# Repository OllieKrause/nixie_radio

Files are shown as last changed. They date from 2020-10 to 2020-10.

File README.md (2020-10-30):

# nixie_radio
A simple FM radio that uses nixie tubes to display frequency and volume. The radio does use a custom PCB so I've included the Autodesk Eagle .brd, .sch, and custom.lib files. I also included the CAM files which are compatible with JLCPCB's cheapest 2 layer PCB manufacturing service.

I want to give a huge thanks to andykarpov for his TEA5767 FM radio library which I've used extensively throughout this project. https://github.com/andykarpov/TEA5767

While the code and hardware have been tested, this project is still very much a work in progress and the user experience has yet to be optimized. 

I hope to document this project in much greater detail once I'm satisfied with the first prototype. 

Questions, comments, suggestions?
Ollie.krause@gmail.com
https://bananascience.net

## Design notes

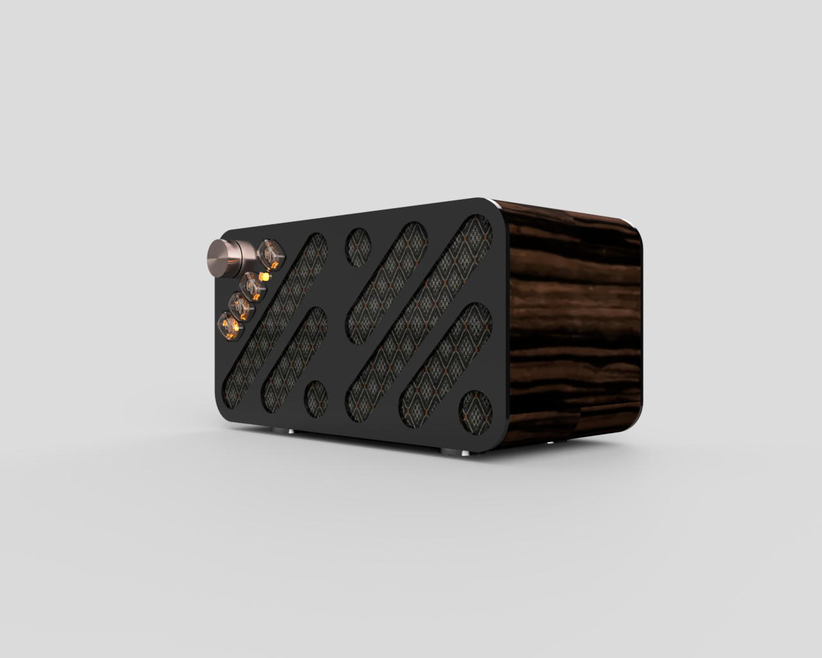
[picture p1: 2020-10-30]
Photos/Nixie Radio Concept 2.3.4.png

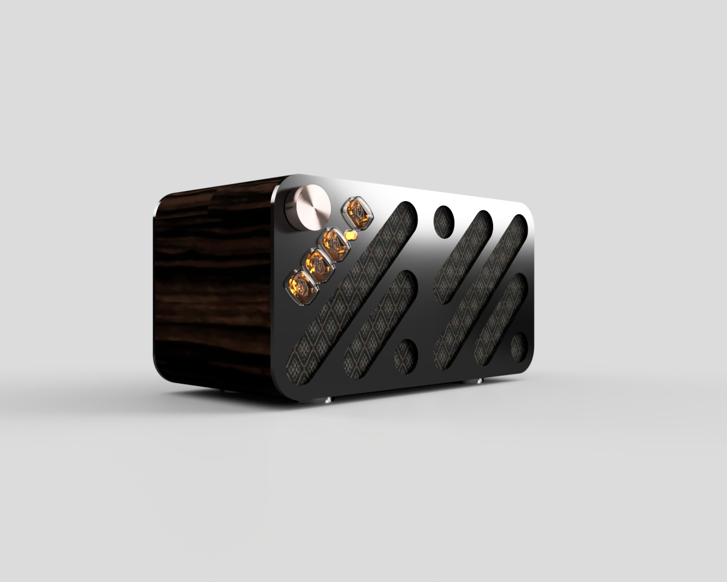
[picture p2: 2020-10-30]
Photos/Nixie Radio Concept 2.3.2.png

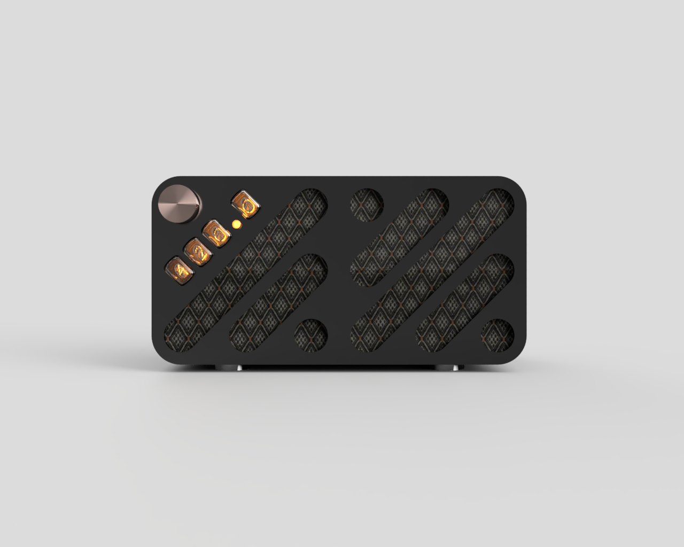
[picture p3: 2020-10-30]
Photos/Nixie Radio Concept 2.3.3.png

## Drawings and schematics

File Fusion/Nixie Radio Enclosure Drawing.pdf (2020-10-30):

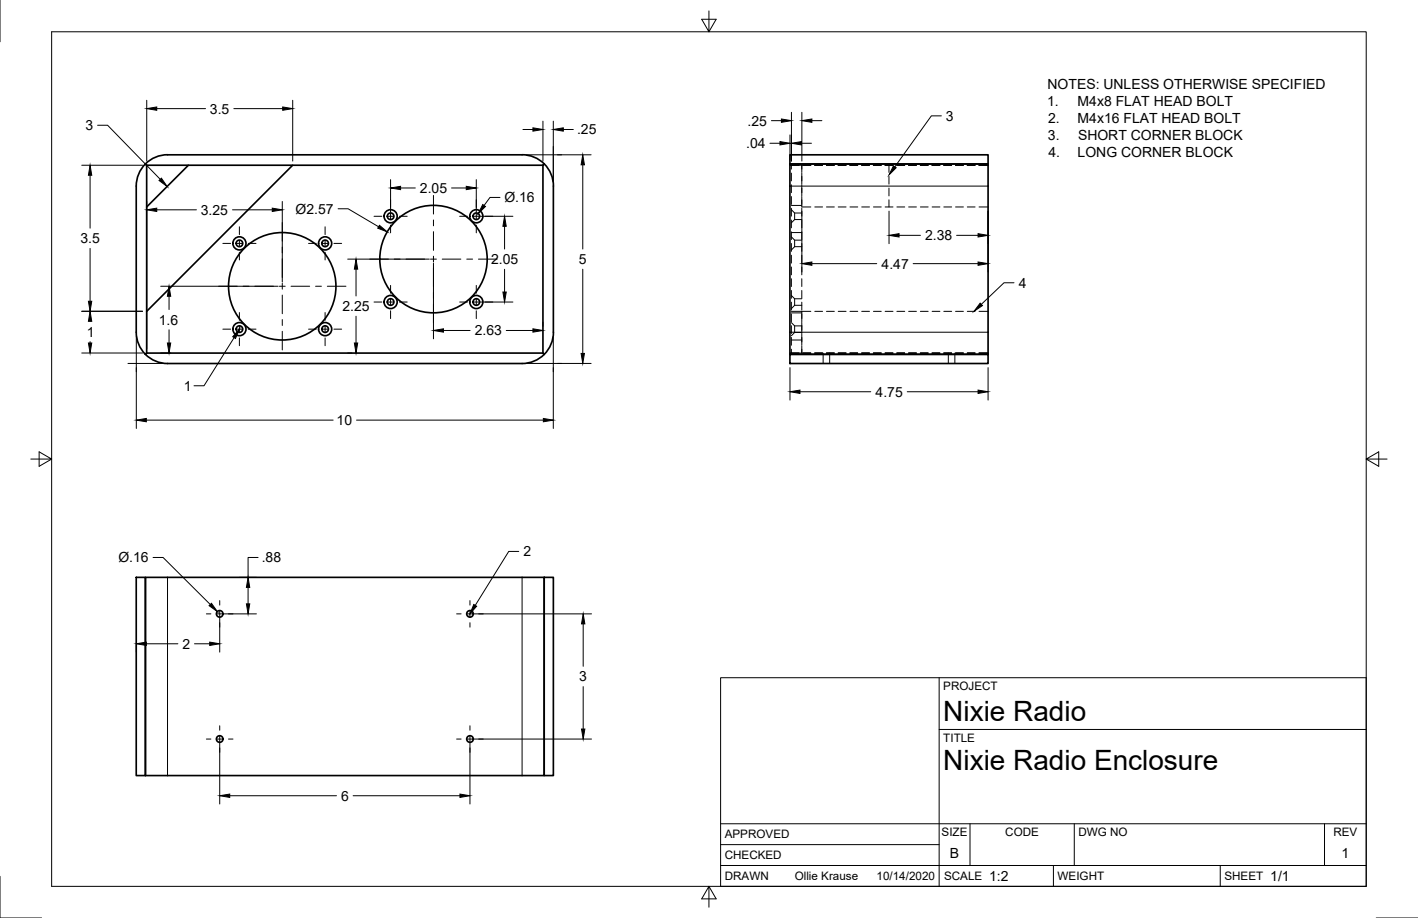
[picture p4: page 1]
SIZE; CODE; DWG NO; REV; Ollie Krause

NOTES: UNLESS OTHERWISE SPECIFIED
1. M4x8 FLAT HEAD BOLT
2. M4x16 FLAT HEAD BOLT
3. SHORT CORNER BLOCK
4. LONG CORNER BLOCK

PROJECT
Nixie Radio
Nixie Radio Enclosure

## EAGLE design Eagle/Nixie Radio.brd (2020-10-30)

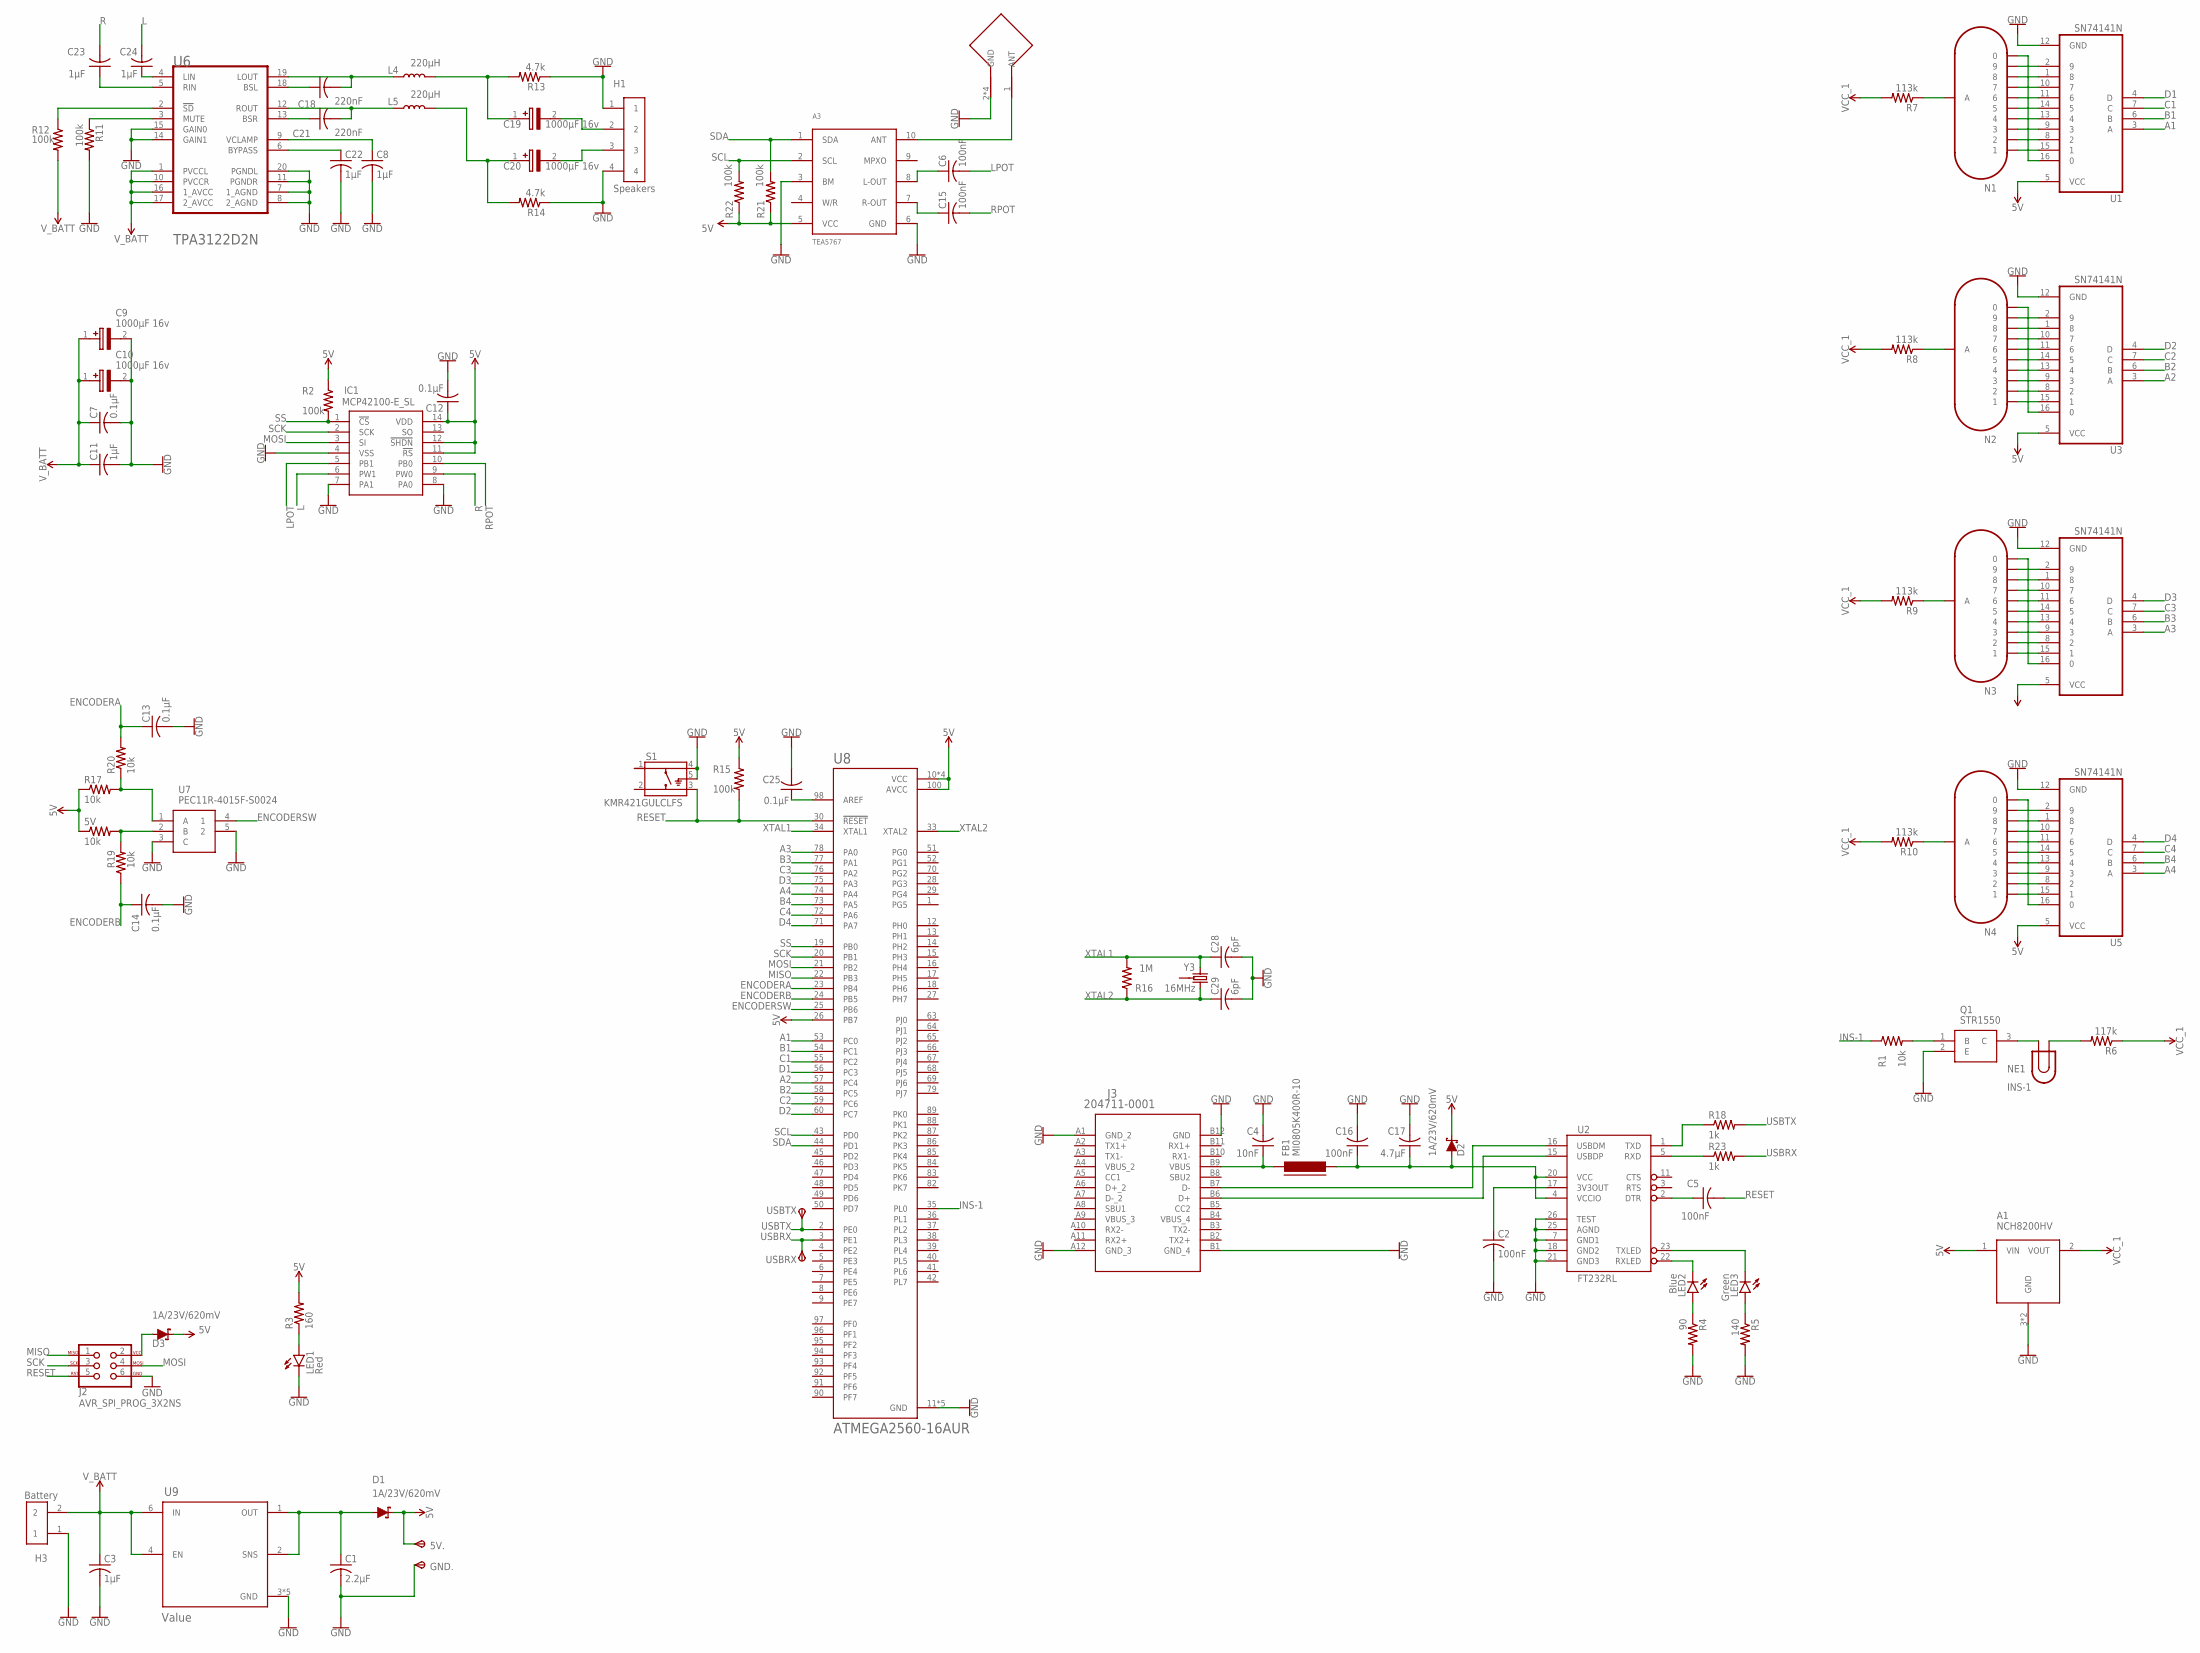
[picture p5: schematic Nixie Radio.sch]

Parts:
5V: 10k; M0805
5V.: TPSTP20R; TP20R
A1: NCH8200HV
A3: TEA5767
AE1: ANTENNA; RFPC-MMCX03-F
C1: 2.2µF; C0805
C2, C5, C6, C15, C16: 100nF; C0805
C3, C8, C11, C22, C23, C24: 1µF; C0805
C4: 10nF; C0805
C7, C12, C13, C14, C25: 0.1µF; C0805
C9, C10, C19, C20: 1000µF 16v; CAPAE1030X1080N
C17: 4.7µF; C0805
C18, C21: 220nF; C0805
C28, C29: 6pF; C0805
D1, D2, D3: 1A/23V/620mV; SOD-323
FB1: MI0805K400R-10; FB805
GND.: TPSTP20R; TP20R
H1: Speakers; 4_PAD_0.1"
H3: Battery; 2_PAD_0.1"
IC1: MCP42100-E_SL; SOIC127P600X175-14N
J2: AVR_SPI_PROG_3X2NS; 2X3-NS
J3: 204711-0001; 204711-0001_MOL
L4, L5: 220µH; 0207ROUND
LED1: Red; SML0805
LED2: Blue; SML0805
LED3: Green; SML0805
N1, N2, N3, N4: IN-17
NE1: INS-1
Q1: STR1550; SOT105P255X140-3N
R1, R17, R19, R20: 10k; M0805
R2, R11, R12, R15, R21, R22: 100k; M0805
R3: 160; M0805
R4: 90; M0805
R5: 140; M0805
R6: 117k; M0805
R7, R8, R9, R10: 113k; M0805
R13, R14: 4.7k; M0805
R16: 1M; M0805
R18, R23: 1k; M0805
S1: KMR421GULCLFS; SW_KMR421GULCLFS
U1, U3, U4, U5: SN74141N; DIP762W46P254L2134H508Q16
U2: FT232RL; SSOP28DB
U6: TEXAS_INSTRUMENTS_TPA3122D2NTEXAS_INSTRUMENTS_TPA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; TEXAS_INSTRUMENTS_TPA3122D2N_0
U7: PEC11R-4015F-S0024; PEC12R-4XXXF-SXXXX_1
U8: ATMEGA2560-16AUR; QFP50P1600X1600X120-100N
U9: Value; 6-WSON
USBRX: TPSTP20R; TP20R
USBTX: TPSTP20R; TP20R
Y3: 16MHz; CRYSTAL-SMD-2X2.5MM

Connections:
5V: 5V.1, 5V..TP, A1.1 (VIN), A3.5 (VCC), C12.1, D1.C, D2.C, D3.C, IC1.11 (!RS), IC1.12 (!SHDN), IC1.14 (VDD), R2.1, R3.2, R15.1, R17.1, R21.1, R22.1, U1.5 (VCC), U3.5 (VCC), U4.5 (VCC), U5.5 (VCC), U8.10 (VCC), U8.26 (PB7), U8.31 (VCC), U8.61 (VCC), U8.80 (VCC), U8.100 (AVCC)
A1: U1.3 (A), U8.53 (PC0)
A2: U3.3 (A), U8.57 (PC4)
A3: U4.3 (A), U8.78 (PA0)
A4: U5.3 (A), U8.74 (PA4)
B1: U1.6 (B), U8.54 (PC1)
B2: U3.6 (B), U8.58 (PC5)
B3: U4.6 (B), U8.77 (PA1)
B4: U5.6 (B), U8.73 (PA5)
C1: U1.7 (C), U8.55 (PC2)
C2: U3.7 (C), U8.59 (PC6)
C3: U4.7 (C), U8.76 (PA2)
C4: U5.7 (C), U8.72 (PA6)
D1: U1.4 (D), U8.56 (PC3)
D2: U3.4 (D), U8.60 (PC7)
D3: U4.4 (D), U8.75 (PA3)
D4: U5.4 (D), U8.71 (PA7)
ENCODERA: C13.1, R20.2, U8.23 (PB4)
ENCODERB: C14.1, R19.1, U8.24 (PB5)
ENCODERSW: U7.4 (1), U8.25 (PB6)
GND: A1.3 (GND), A1.4 (GND), A3.3 (BM), A3.6 (GND), AE1.2 (GND), AE1.3 (GND), AE1.4 (GND), AE1.5 (GND), C1.2, C2.2, C3.2, C4.2, C7.2, C8.2, C9.2 (-), C10.2 (-), C11.2, C12.2, C13.2, C14.2, C16.2, C17.2, C22.2, C25.2, C28.2, C29.2, GND..TP, H1.1, H1.4, H3.1, IC1.4 (VSS), IC1.7 (PA1), IC1.8 (PA0), J2.6, J3.A1 (GND_2), J3.A12 (GND_3), J3.B1 (GND_4), J3.B12 (GND), LED1.C, Q1.2 (E), R4.2, R5.2, R11.2, R13.1, R14.1, S1.4, S1.5 (G), U1.12 (GND), U2.7 (GND1), U2.18 (GND2), U2.21 (GND3), U2.25 (AGND), U2.26 (TEST), U3.12 (GND), U4.12 (GND), U5.12 (GND), U6.7 (1_AGND), U6.8 (2_AGND), U6.11 (PGNDR), U6.14 (GAIN1), U6.15 (GAIN0), U6.20 (PGNDL), U7.3 (C), U7.5 (2), U8.11 (GND), U8.32 (GND), U8.62 (GND), U8.81 (GND), U8.99 (GND), U9.3 (GND), U9.5 (GND), U9.7 (GND), U9.8 (GND), U9.9 (GND), Y3.P2 (GND), Y3.P4 (GND)
INS-1: R1.1, U8.35 (PL0)
L: C24.2, IC1.6 (PW1)
LPOT: C6.2, IC1.5 (PB1)
MISO: J2.1, U8.22 (PB3)
MOSI: IC1.3 (SI), J2.4, U8.21 (PB2)
unnamed: C4.1, FB1.1, J3.B9 (VBUS)
unnamed: NE1.2, Q1.3 (C)
unnamed: NE1.1, R6.2
unnamed: C5.1, U2.2 (DTR)
unnamed: C2.1, U2.17 (3V3OUT)
unnamed: LED1.A, R3.1
unnamed: C16.1, C17.1, D2.A, FB1.2, U2.4 (VCCIO), U2.20 (VCC)
unnamed: C1.1, D1.A, U9.1 (OUT), U9.2 (SNS)
unnamed: Q1.1 (B), R1.2
unnamed: N1.1, U1.15 (1)
unnamed: J3.B6 (D+), U2.15 (USBDP)
unnamed: J3.B7 (D-), U2.16 (USBDM)
unnamed: R18.1, U2.1 (TXD)
unnamed: N1.2, U1.8 (2)
unnamed: N1.3, U1.9 (3)
unnamed: N1.4, U1.13 (4)
unnamed: N1.5, U1.14 (5)
unnamed: N1.6, U1.11 (6)
unnamed: N1.7, U1.10 (7)
unnamed: N1.8, U1.1 (8)
unnamed: N1.9, U1.2 (9)
unnamed: N1.0, U1.16 (0)
unnamed: N1.A, R7.1
unnamed: N2.1, U3.15 (1)
unnamed: N2.2, U3.8 (2)
unnamed: N2.3, U3.9 (3)
unnamed: N2.4, U3.13 (4)
unnamed: N2.5, U3.14 (5)
unnamed: N2.6, U3.11 (6)
unnamed: N2.7, U3.10 (7)
unnamed: N2.8, U3.1 (8)
unnamed: N2.9, U3.2 (9)
unnamed: N2.0, U3.16 (0)
unnamed: N2.A, R8.1
unnamed: N3.1, U4.15 (1)
unnamed: N3.2, U4.8 (2)
unnamed: N3.3, U4.9 (3)
unnamed: N3.4, U4.13 (4)
unnamed: N3.5, U4.14 (5)
unnamed: N3.6, U4.11 (6)
unnamed: N3.7, U4.10 (7)
unnamed: N3.8, U4.1 (8)
unnamed: N3.9, U4.2 (9)
unnamed: N3.0, U4.16 (0)
unnamed: N3.A, R9.1
unnamed: N4.1, U5.15 (1)
unnamed: N4.2, U5.8 (2)
unnamed: N4.3, U5.9 (3)
unnamed: N4.4, U5.13 (4)
unnamed: N4.5, U5.14 (5)
unnamed: N4.6, U5.11 (6)
unnamed: N4.7, U5.10 (7)
unnamed: N4.8, U5.1 (8)
unnamed: N4.9, U5.2 (9)
unnamed: N4.0, U5.16 (0)
unnamed: N4.A, R10.1
unnamed: LED2.A, R4.1
unnamed: C8.1, U6.9 (VCLAMP)
unnamed: A3.10 (ANT), AE1.1 (ANT)
unnamed: R11.1, U6.3 (MUTE)
unnamed: R12.1, U6.2 (!SD!)
unnamed: R23.1, U2.5 (RXD)
unnamed: C18.2, L4.1, U6.19 (LOUT)
unnamed: C18.1, U6.18 (BSL)
unnamed: C19.2 (-), H1.2
unnamed: C20.1 (+), L5.2, R14.2
unnamed: C20.2 (-), H1.3
unnamed: C21.1, U6.13 (BSR)
unnamed: LED2.C, U2.22 (RXLED)
unnamed: C22.1, U6.6 (BYPASS)
unnamed: C23.1, U6.5 (RIN)
unnamed: C24.1, U6.4 (LIN)
unnamed: C19.1 (+), L4.2, R13.2
unnamed: C21.2, L5.1, U6.12 (ROUT)
unnamed: LED3.C, U2.23 (TXLED)
unnamed: C25.1, U8.98 (AREF)
unnamed: R17.2, R20.1, U7.1 (A)
unnamed: LED3.A, R5.1
unnamed: 5V.2, R19.2, U7.2 (B)
unnamed: A3.8 (L-OUT), C6.1
unnamed: A3.7 (R-OUT), C15.1
unnamed: D3.A, J2.2
R: C23.2, IC1.9 (PW0)
RESET: C5.2, J2.5, R15.2, S1.3, U8.30 (!RESET)
RPOT: C15.2, IC1.10 (PB0)
SCK: IC1.2 (SCK), J2.3, U8.20 (PB1)
SCL: A3.2 (SCL), R22.2, U8.43 (PD0)
SDA: A3.1 (SDA), R21.2, U8.44 (PD1)
SS: IC1.1 (!CS), R2.2, U8.19 (PB0)
USBRX: R23.2, U8.3 (PE1), USBRX.TP
USBTX: R18.2, U8.2 (PE0), USBTX.TP
VBUS_2: J3.A4 (VBUS_2)
VBUS_3: J3.A9 (VBUS_3)
VBUS_4: J3.B4 (VBUS_4)
VCC_1: A1.2 (VOUT), R6.1, R7.2, R8.2, R9.2, R10.2
V_BATT: C3.1, C7.1, C9.1 (+), C10.1 (+), C11.1, H3.2, R12.2, U6.1 (PVCCL), U6.10 (PVCCR), U6.16 (1_AVCC), U6.17 (2_AVCC), U9.4 (EN), U9.6 (IN)
XTAL1: C28.1, R16.2, U8.34 (XTAL1), Y3.P1 (1)
XTAL2: C29.1, R16.1, U8.33 (XTAL2), Y3.P3 (2)

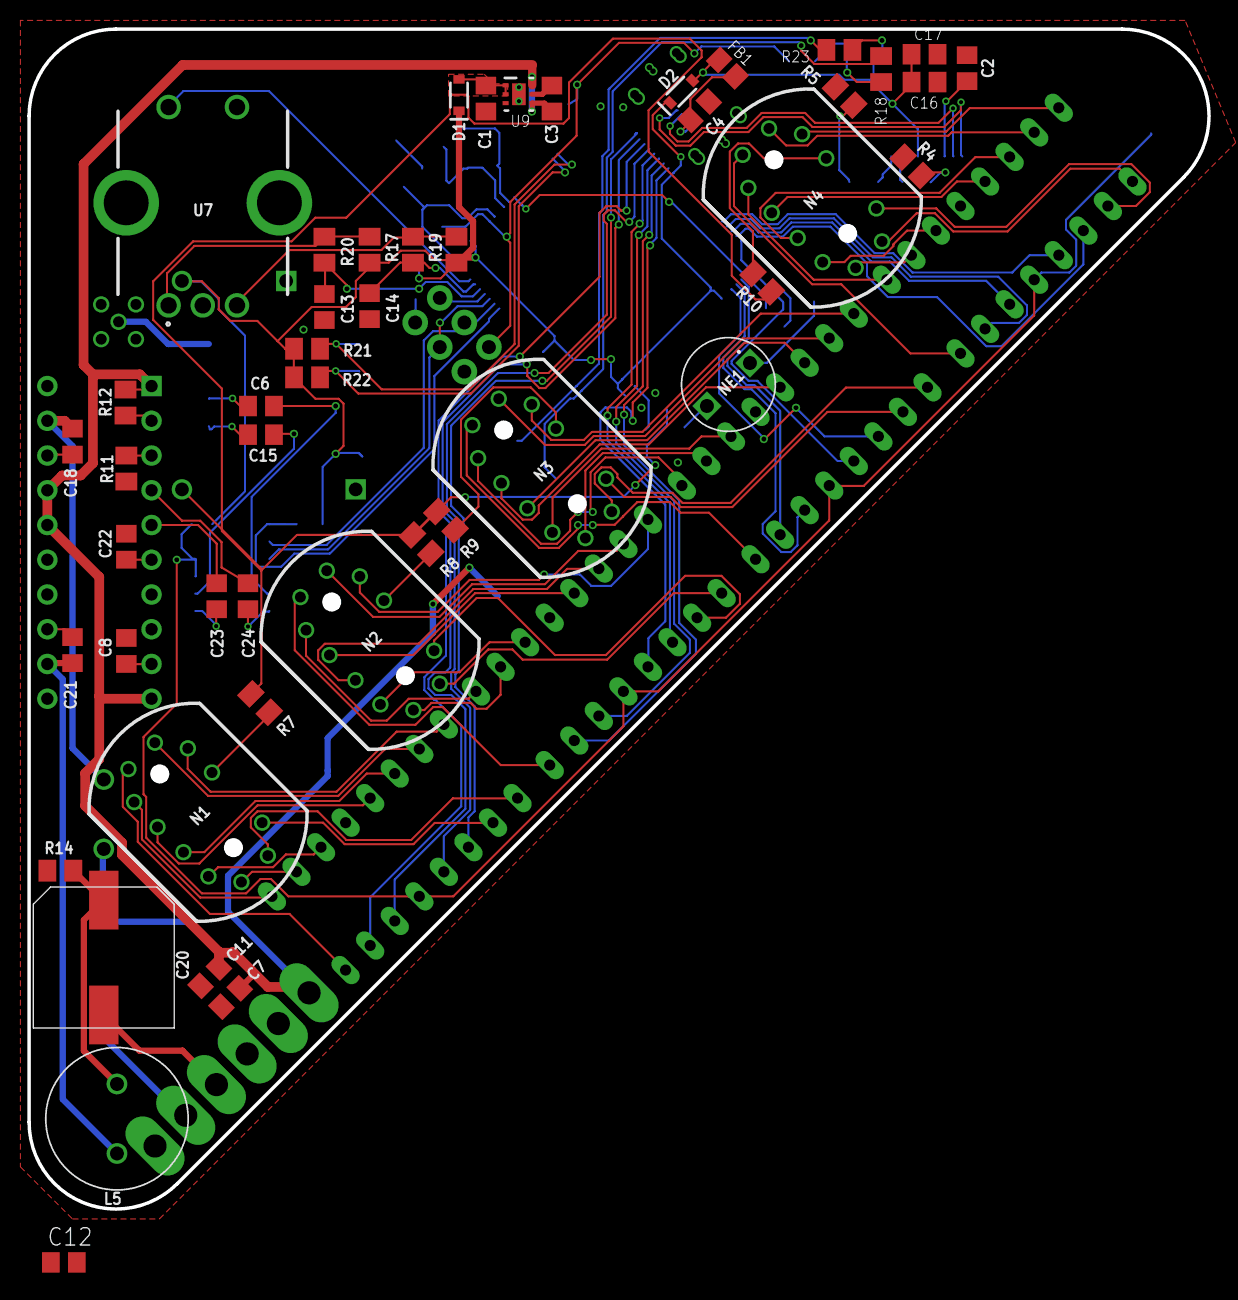
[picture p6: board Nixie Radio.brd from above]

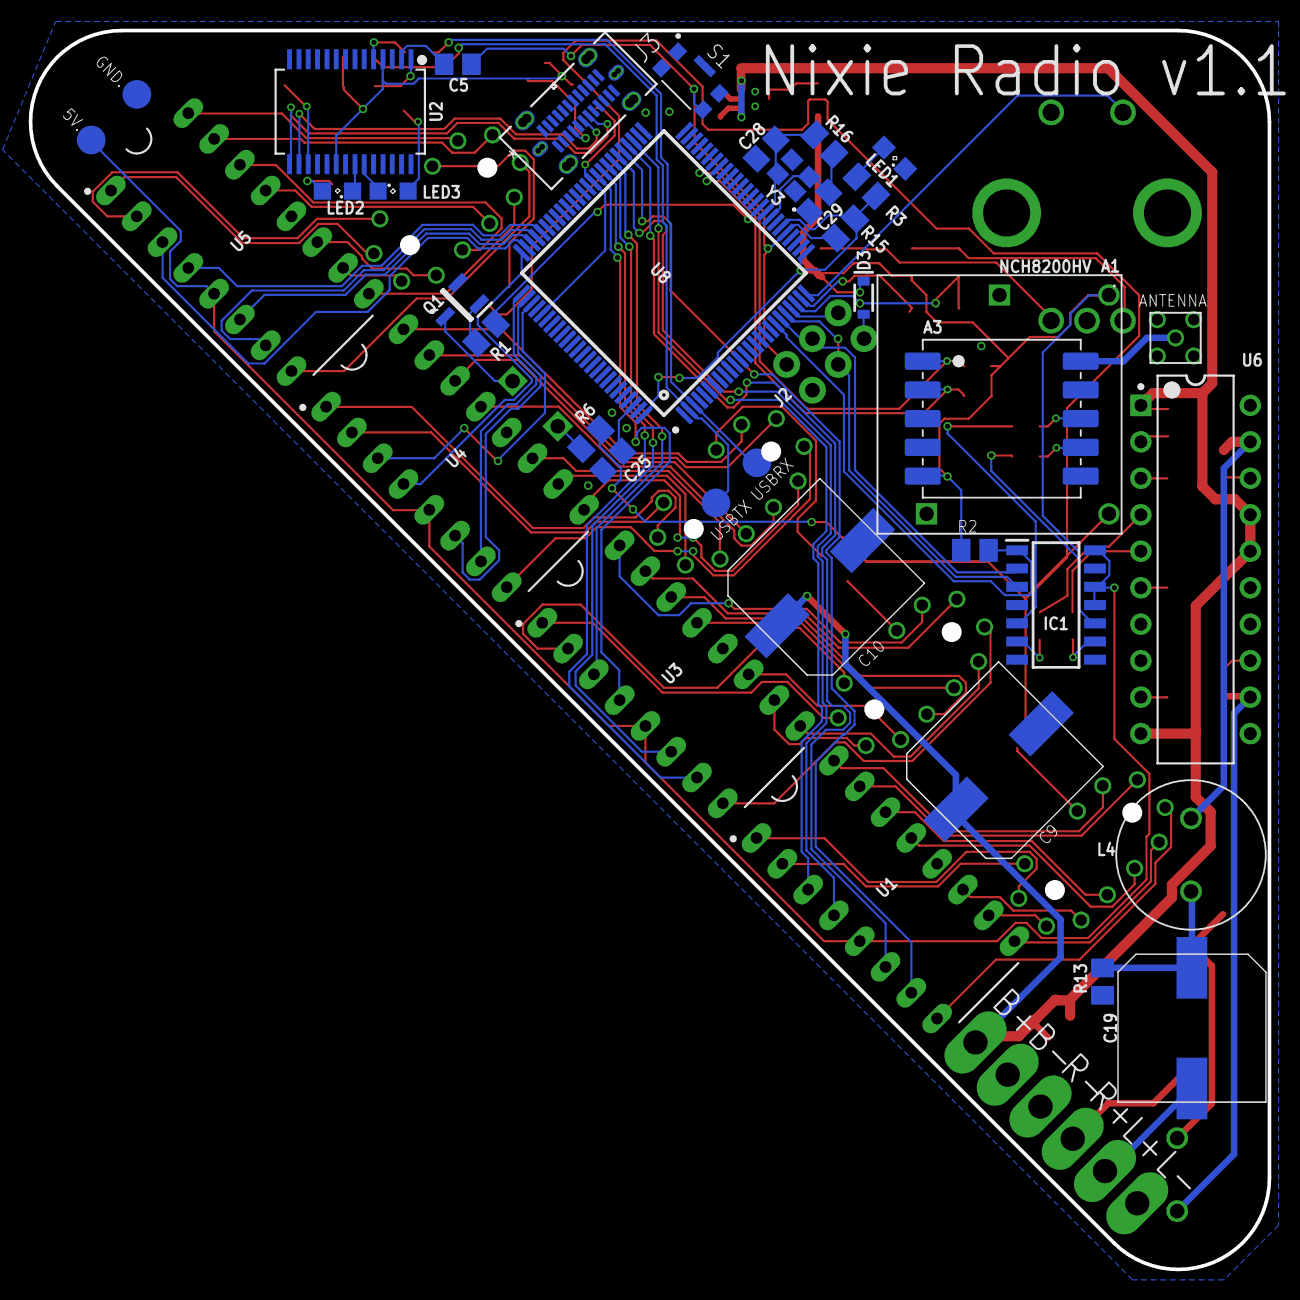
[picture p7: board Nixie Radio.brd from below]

Board: 2 copper layers, 86.3 x 86.3 mm, 89 parts (41 on the bottom side), 121 nets.

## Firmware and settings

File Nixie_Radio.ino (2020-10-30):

/*
  Nixie Radio Firmware v1.0
  Author: Ollie K
  License: Creative Commons Non Commercial
  Last updated: October 2020
  /*

  /*
  THINGS TO ADD/QUESTIONS
  -WHEN TO USE DEFINE AND WHEN TO USE CONSTINT
  -MOVE ALL DEFINES AND CONST INTS TO A SEPARATE HEADER FILE
*/

// Libraries
#include <Wire.h>
#include "TEA5767.h"
#include <EEPROM.h>
#include <SPI.h>

// Rotary encoder inputs
#define encoderA 10
#define encoderB 11
#define encoderSW 12

// Number of nixie tubes (number of digits)
#define digits 4

// Nixie tube pins
#define decimalPin 49

uint8_t nixiePinArray[] = {30, 31, 32, 33, 34, 35, 36, 37, 22, 23, 24, 25, 26, 27, 28, 29}; // Array of nixie tube pins. Must be in A1, B1, C1, D1, A2, B2, etc order.

bool nixieEnable = false; // Set to true to turn on nixie tubes

TEA5767 Radio; // Create instance of radio

// Bool to determine if the user is adjusting the frequency or volume
bool inputState = true; // true -> changing frequency | false -> changing volume

// Rotary encoder global variables
int currentStateA;
int lastStateA;
unsigned long lastButtonPress = 0;
bool encoderDirection; // 0 -> CW 1 -> CCW

// TEA5767 FM radio global variables
const uint16_t minFrequency = 880; // Minimum frequency as an integer (top end reset)
const uint16_t maxFrequency = 1070; // Maximum frequency as an integer (bottom end reset)

// Data stored to EEPROM - will eventually use a struct and wear leveling
uint16_t frequency = 1055; // Frequency as an integer to simplify bit math. Divided by 10 when sent to radio.
uint8_t volume = 100; // Volume as a number from 0-100

int eeAddress = 0; // EEPROM address where EEPROMdata struct will be stored

#define potCs 53 // MCP42100 chip select pin

// Configure SPI settings
SPISettings spiSettings(20000000, MSBFIRST, SPI_MODE0);

/*
   --SETUP FUNCTION--
   CONFIGURES I/O
   RESTORES EEPROM VALUES
*/
void setup() {
  Serial.begin(9600); // Setup serial monitor

  Wire.begin(); // Enable I2C communication

  SPI.begin(); // Enable SPI communication

  Radio.init(); // Initialize TEA5767 radio & mute the voliume

  Serial.println(F("----- Nixie Radio v1.1 -----")); // Write version number to serial monitor on bootup

  frequency = EEPROM.get(eeAddress, frequency);  // Read frequency from EEPROM

  volume = 50; // Arbitrary default volume level to check mute features until I get it properly stored in EEPROM

  frequency++; // Add one to frequency because EEPROM always seems to record frequency-1

  Serial.print(F("EEPROM recovered. ")); // Print recovered frequency

  muteHard(); // Mute radio while radio changes frequency

  changeFrequency(); // Tune radio to recovered frequency

  pinMode(encoderA, INPUT); // Set encoder pins as inputs
  pinMode(encoderB, INPUT);
  pinMode(encoderSW, INPUT_PULLUP);

  pinMode(potCs, OUTPUT); // Configure pot chip select as output
  digitalWrite(potCs, HIGH); // Pot chip select default to de-selected

  // Define nixie tube pins as outputs
  for (int i = 0; i < (digits * 4) - 1; i++) {
    pinMode(nixiePinArray[i], OUTPUT);
  }

  pinMode(decimalPin, OUTPUT); // Define decimal (INS-1) pin as an output

  lastStateA = digitalRead(encoderA); // Read the initial state of encoderA

  nixieEnable = true;

  setNixie(0000); // Write nixie tubes to 0 while booting

  delay (4000); // Delay 2 seconds to allow radio to tune into last station.

  unmuteSoft(); // Soft unmute radio now that it's tuned into the proper station

  setNixie(frequency); // Set nixies to recovered frequency

  Serial.println(F("Setup complete"));
}

/*
   --MAIN LOOP FUNCTION--
   CALLS "readEncoder" function
*/

void loop() {
  readEncoder(); // Read encoder position and update respective values
}

/*
  --READ ENCODER FUNCTION--
  READS ENCODER ROTATION DIRECTION AND BUTTON STATE
  CHECKS USER INPUT STATE (VOLUME OR FREQUENCY)
  CALLS "changeFrequency" AND "changeVolume" FUNCTIONS
*/

void readEncoder() {
  currentStateA = digitalRead(encoderA); // Read the current state of encoderA

  // If last and current state of encoderA are different, then pulse occurred. React to only 1 state change to avoid double count
  if (currentStateA != lastStateA  && currentStateA == 1) {
    // If the encoderB is different than the encoderA state then the encoder is rotating CW
    if (digitalRead(encoderB) != currentStateA) {
      encoderDirection = 1;
    }
    else {
      encoderDirection = 0;
    }

    // Check user's input mode
    if (inputState) {
      changeFrequency(); // Change frequency
    }
    else {
      changeVolume(); // Change frequency
    }
  }

  lastStateA = currentStateA; // Remember last CLK state

  int btnState = digitalRead(encoderSW); // Read the button state

  //If detect LOW signal, button is pressed
  if (btnState == LOW) {
    //if at least 50ms have passed since last LOW pulse, button has been pressed and released
    if (millis() - lastButtonPress > 50) {

      // Change to opposite input state
      if (inputState) {
        inputState = false;
      }
      else {
        inputState = true;
      }

      Serial.print(F("Input state changed: "));
      Serial.println((inputState ? "Frequency" : "Volume"));

    }
    lastButtonPress = millis(); // Remember last button press event
  }
  delay(1); // Small delay to debounce the reading
}

/*
   --CHANGE FREQUENCY FUNCTION--
   TAKES ENCODER DIRECTION AS INPUT
   INCREASES OR DECREASES FREQUENCY
   SENDS FREQUENCY TO "void setNixie"
*/

void changeFrequency() {
  // Increase frequency if encoder is turned CW
  if (encoderDirection) {
    if (frequency <= maxFrequency) {
      frequency = frequency + 1; // Increase frequency by 1/10MHz (1 because divided by 10 when sent to radio)
    }
    else {
      frequency = minFrequency;
      Serial.println(F("Top end reset"));
    }
  }

  // Decrease frequency if encoder is turned CW
  else {
    if (frequency >= minFrequency) {
      frequency = frequency - 1; // Decrease frequency by 1/10MHz (1 because divided by 10 when sent to radio)
    }
    else {
      frequency = maxFrequency;
      Serial.println(F("Bottom end reset"));
    }
  }

  // Set radio frequency
  Radio.set_frequency((float)frequency / 10.0);

  // Write current frequency to serial monitor
  Serial.print(F("Frequency: "));
  Serial.println((float)frequency / 10.0);

  // Write current radio frequency to EEPROM
  EEPROM.put(eeAddress, frequency);

  setNixie(frequency); // Call function to set nixie tubes
}

/*
   --CHANGE VOLUME FUNCTION--
   TAKES ENCODER DIRECTION AS INPUT
   INCREASES OR DECREASES VOLUME
   SENDS VOLUME TO "void setNixie"
*/

void changeVolume () {
  if (encoderDirection) {
    if (volume < 100) {
      volume ++;
    }
    else {
      volume = 100;
    }
  }

  if (!encoderDirection) {
    if (volume > 0) {
      volume --;
    }
    else {
      volume = 0;
    }
  }

  uint8_t volumeActual = map(volume, 0, 100, 255, 0); // Local volume variable remapped for digital pot input range

  SPI.beginTransaction(spiSettings); // Begin SPI transaction
  digitalWrite(potCs, LOW); // Select pot chip
  SPI.transfer(0b00010011); // Select both pots as address and enter write data mode
  SPI.transfer(volumeActual); // Send volume to pot
  digitalWrite(potCs, HIGH); // Deselect pot chip
  SPI.endTransaction(); // End SPI transaction

  // Write current frequency to serial monitor
  Serial.print(F("Volume: "));
  Serial.println(volume);

  //EEPROM.put(eeAddress + sizeof(frequency), volume); // Write volume to EEPROM in the bits right after

  setNixie((unsigned int)volume * 10); // Call function to set nixie tubes. Multiply volume by 10 to shift over one decimal place.

}


/*
   --SET NIXIE FUNCTION--
  TAKES A NUMBER AS AN INPUT
  SEPARATES NUMBER INTO BYTE ARRAY
  EXTRACTS 0-9 BITS FROM EACH BYTE AND SENDS TO NIXIE TUBES
*/

void setNixie(uint16_t nixieVal) {
  uint8_t digitArray[digits]; // Separate number into individual digits within an array.
  for (int i = digits - 1; i >= 0; i--) { // Array is zero indexing so start at digits - 1.
    digitArray[i] = nixieVal % 10; // Modulo the number to isolate last digit
    nixieVal = floor((float) nixieVal / 10.0); // Divide number by 10 to knock off the last digit
  }

  if (nixieEnable == true) { // Only write to nixies if tubes are enabled
    digitalWrite(decimalPin, HIGH); // Turn on decimal (INS-1)
    for (int i = 0; i < digits; i++) { // i represents each nixie tube digit
      //Serial.print(F(" | "));
      //Serial.print(digitArray[i]); // Now that frequency digits are separated into digitArray, print out each separated digit to verify the separation

      int c = 0; // Used to identify which of the four bits in each digit is being controlled

      for (int mask = 0b0001; mask < 0b1000; mask <<= 1 ) { // Use a bitmask to extract the 4 bits from each digit
        if (digitArray[i] & mask) { // Check if each bit is HIGH or LOW.
          digitalWrite(nixiePinArray[(i * 4) + c], HIGH); // Write corresponding nixie pin HIGH. i*4 because each nixie tube is driven by a nibble
        }
        else {
          digitalWrite(nixiePinArray[(i * 4) + c], LOW); // Else write corresponding nixie pin LOW.
        }
        c++; // Add to c to move on to next bit
      }
    }
  }
  else {
    for (int i = 0; i < sizeof(nixiePinArray); i++) {
      digitalWrite(nixiePinArray[i], HIGH); // Write all nixie pins high to turn off all tubes
      digitalWrite(decimalPin, LOW); // Turn off decimal (INS-1)
    }
  }
}

/*
   --HARD MUTE FUNCTION--
  IMMEDIATELY MUTES RADIO VOLUME
*/

void muteHard () {
  SPI.beginTransaction(spiSettings); // Begin SPI transaction
  digitalWrite(potCs, LOW); // Select pot chip
  SPI.transfer(0b00010011); // Select both pots as address and enter write data mode
  SPI.transfer(255); // Set maxmimum pot resistance
  digitalWrite(potCs, HIGH); // Deselect pot chip
  SPI.endTransaction(); // End SPI transaction
}

/*
   --SOFT MUTE FUNCTION--
  QUICKLY FADES OUT RADIO VOLUME
*/

void muteSoft() {
  for (int i = map(volume, 0, 100, 255, 0); i < 255; i++) {
    SPI.beginTransaction(spiSettings); // Begin SPI transaction
    digitalWrite(potCs, LOW); // Select pot chip
    SPI.transfer(0b00010011); // Select both pots as address and enter write data mode
    SPI.transfer(i); // Fade out volume
    digitalWrite(potCs, HIGH); // Deselect pot chip
    SPI.endTransaction(); // End SPI transaction
    delay(10);
  }
}

/*
   --HARD UNMUTE FUNCTION--
  IMMEDIATELY UNMUTES RADIO VOLUME
*/

void unmuteHard () {
  SPI.beginTransaction(spiSettings); // Begin SPI transaction
  digitalWrite(potCs, LOW); // Select pot chip
  SPI.transfer(0b00010011); // Select both pots as address and enter write data mode
  SPI.transfer(0); // Set minimum pot resistance
  digitalWrite(potCs, HIGH); // Deselect pot chip
  SPI.endTransaction(); // End SPI transaction
}

/*
   --SOFT UNMUTE FUNCTION--
  QUICKLY FADES IN RADIO VOLUME
*/

void unmuteSoft() {
  for (int i = 255; i > map(volume, 0, 100, 255, 0); i--) {
    SPI.beginTransaction(spiSettings); // Begin SPI transaction
    digitalWrite(potCs, LOW); // Select pot chip
    SPI.transfer(0b00010011); // Select both pots as address and enter write data mode
    SPI.transfer(i); // Fade in volume
    digitalWrite(potCs, HIGH); // Deselect pot chip
    SPI.endTransaction(); // End SPI transaction
    delay(10);
  }
}

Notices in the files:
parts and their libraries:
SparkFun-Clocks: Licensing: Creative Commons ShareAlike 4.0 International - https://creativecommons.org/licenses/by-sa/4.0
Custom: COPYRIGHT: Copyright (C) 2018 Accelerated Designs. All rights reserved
